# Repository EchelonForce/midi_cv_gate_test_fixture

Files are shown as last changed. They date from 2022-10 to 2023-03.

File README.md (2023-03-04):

# MIDI to 16x16 CV Gate Module Test Fixture

This the KiCAD design of a test fixture for the MIDI to 16x16 CV Gate Module

Full writeup here: https://www.robotdialogs.com/2023/03/test-fixture-and-calibration-eurorack.html

This work is licensed under a Creative Commons Attribution-NonCommercial-ShareAlike 4.0 International License. https://creativecommons.org/licenses/by-nc-sa/4.0/

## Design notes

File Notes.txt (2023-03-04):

Changed to 11k resistors to bring 10V under the 4.936 reference from the shunt diode.

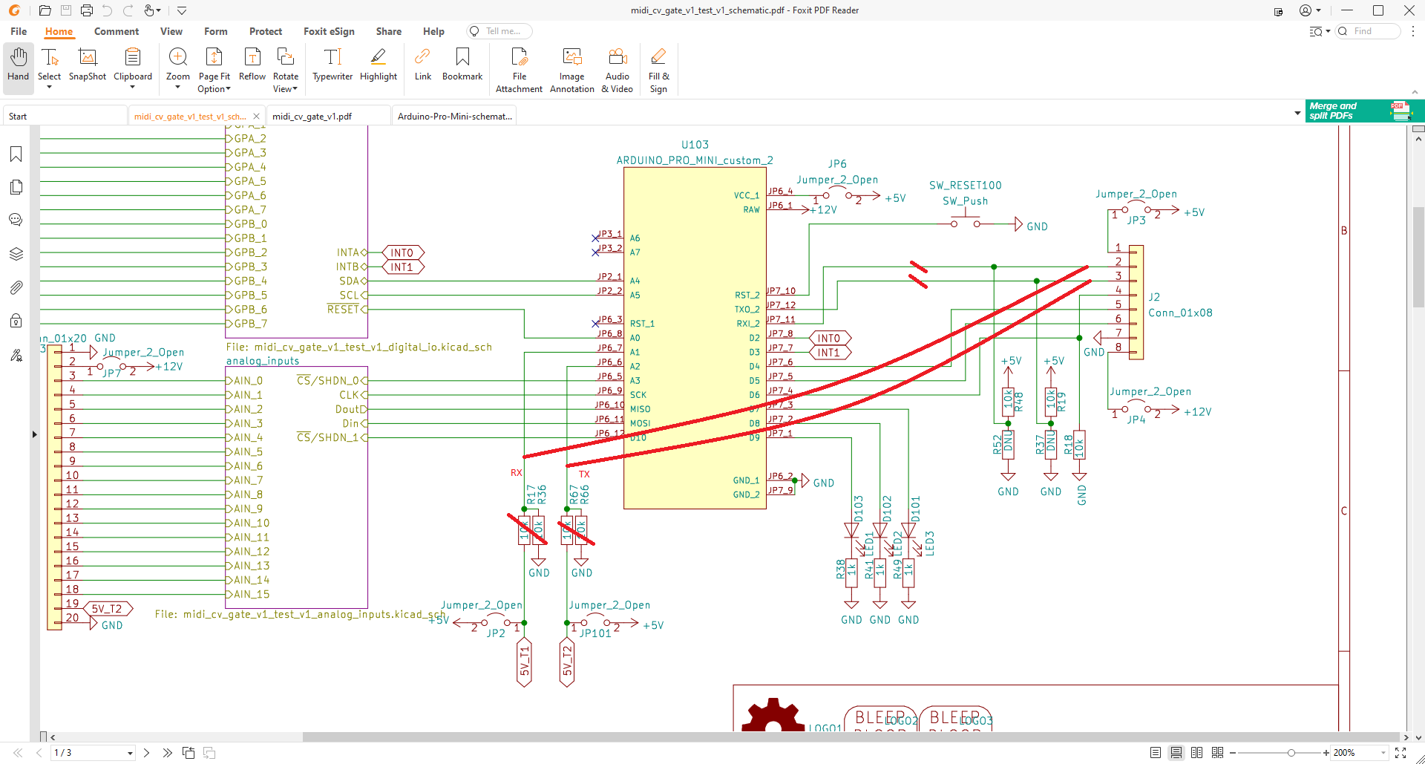
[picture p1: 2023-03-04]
Rework for Software Serial.png

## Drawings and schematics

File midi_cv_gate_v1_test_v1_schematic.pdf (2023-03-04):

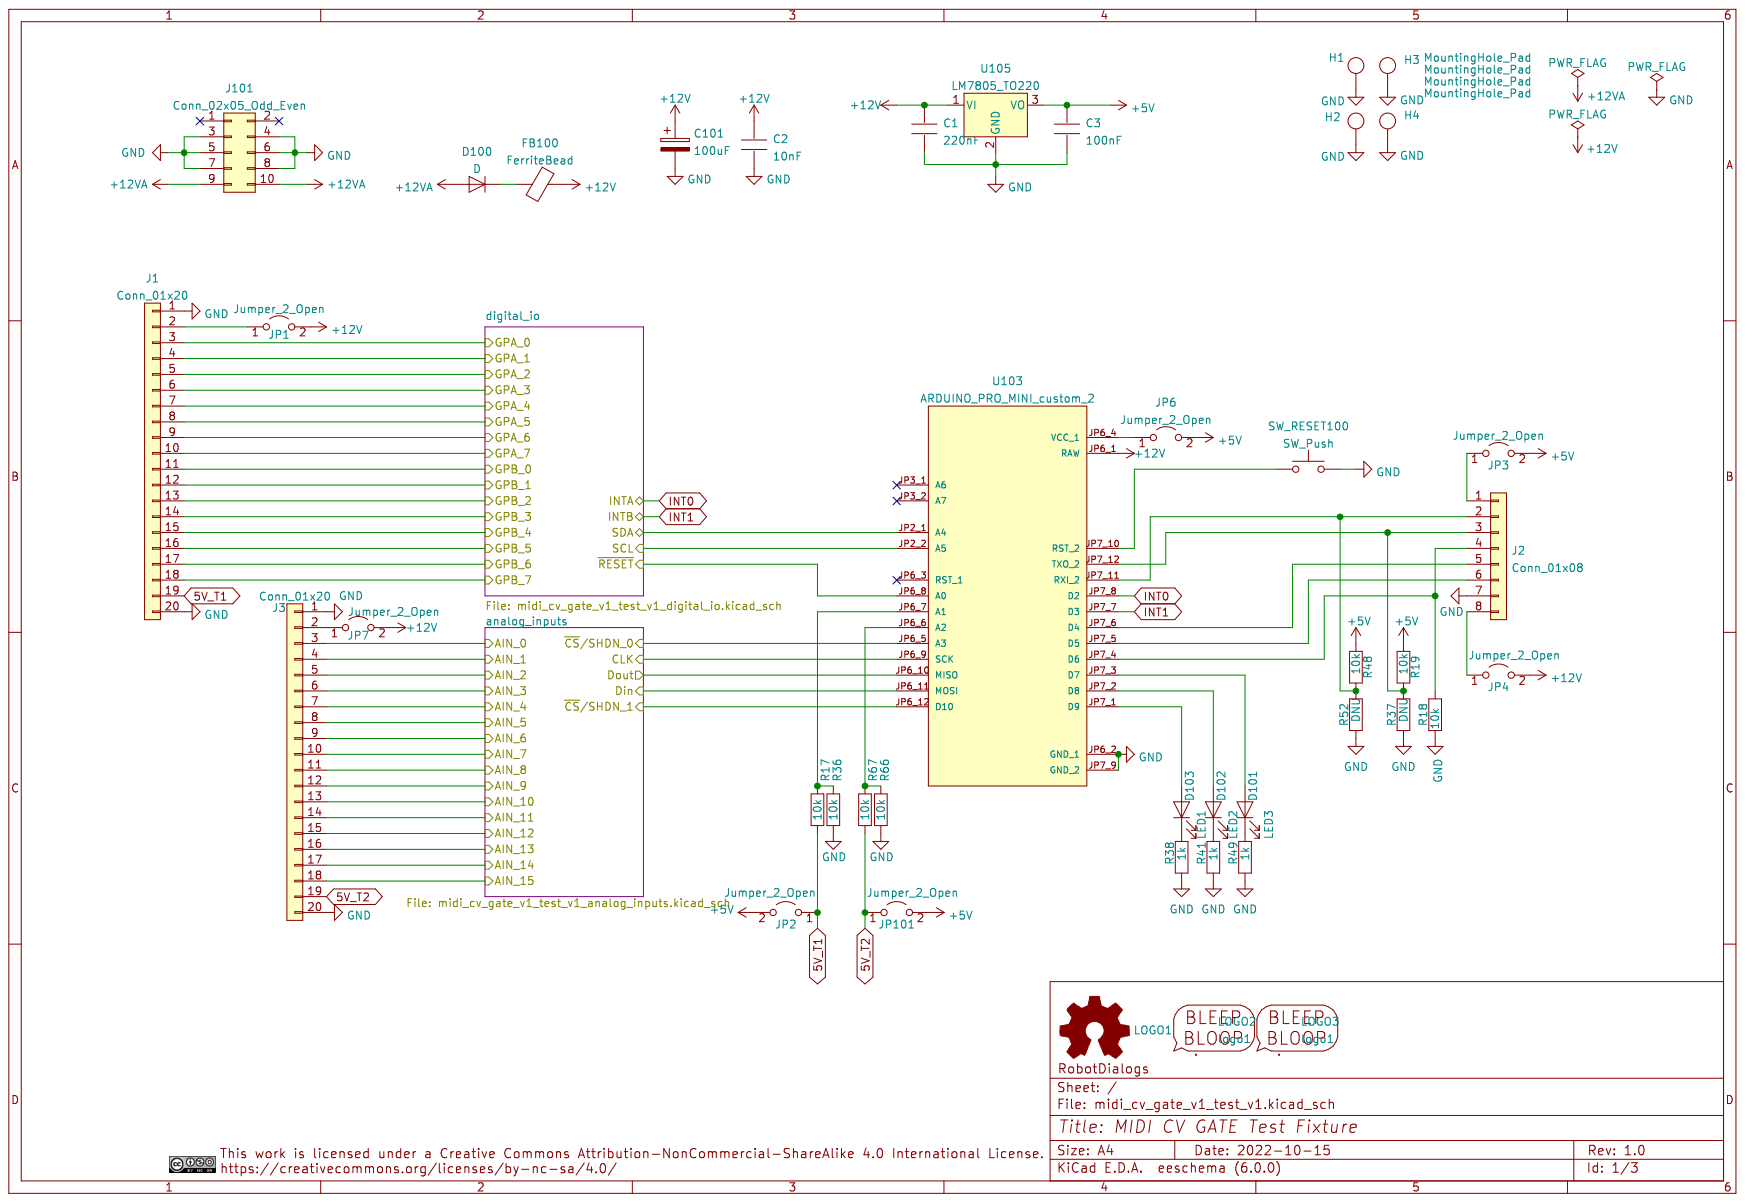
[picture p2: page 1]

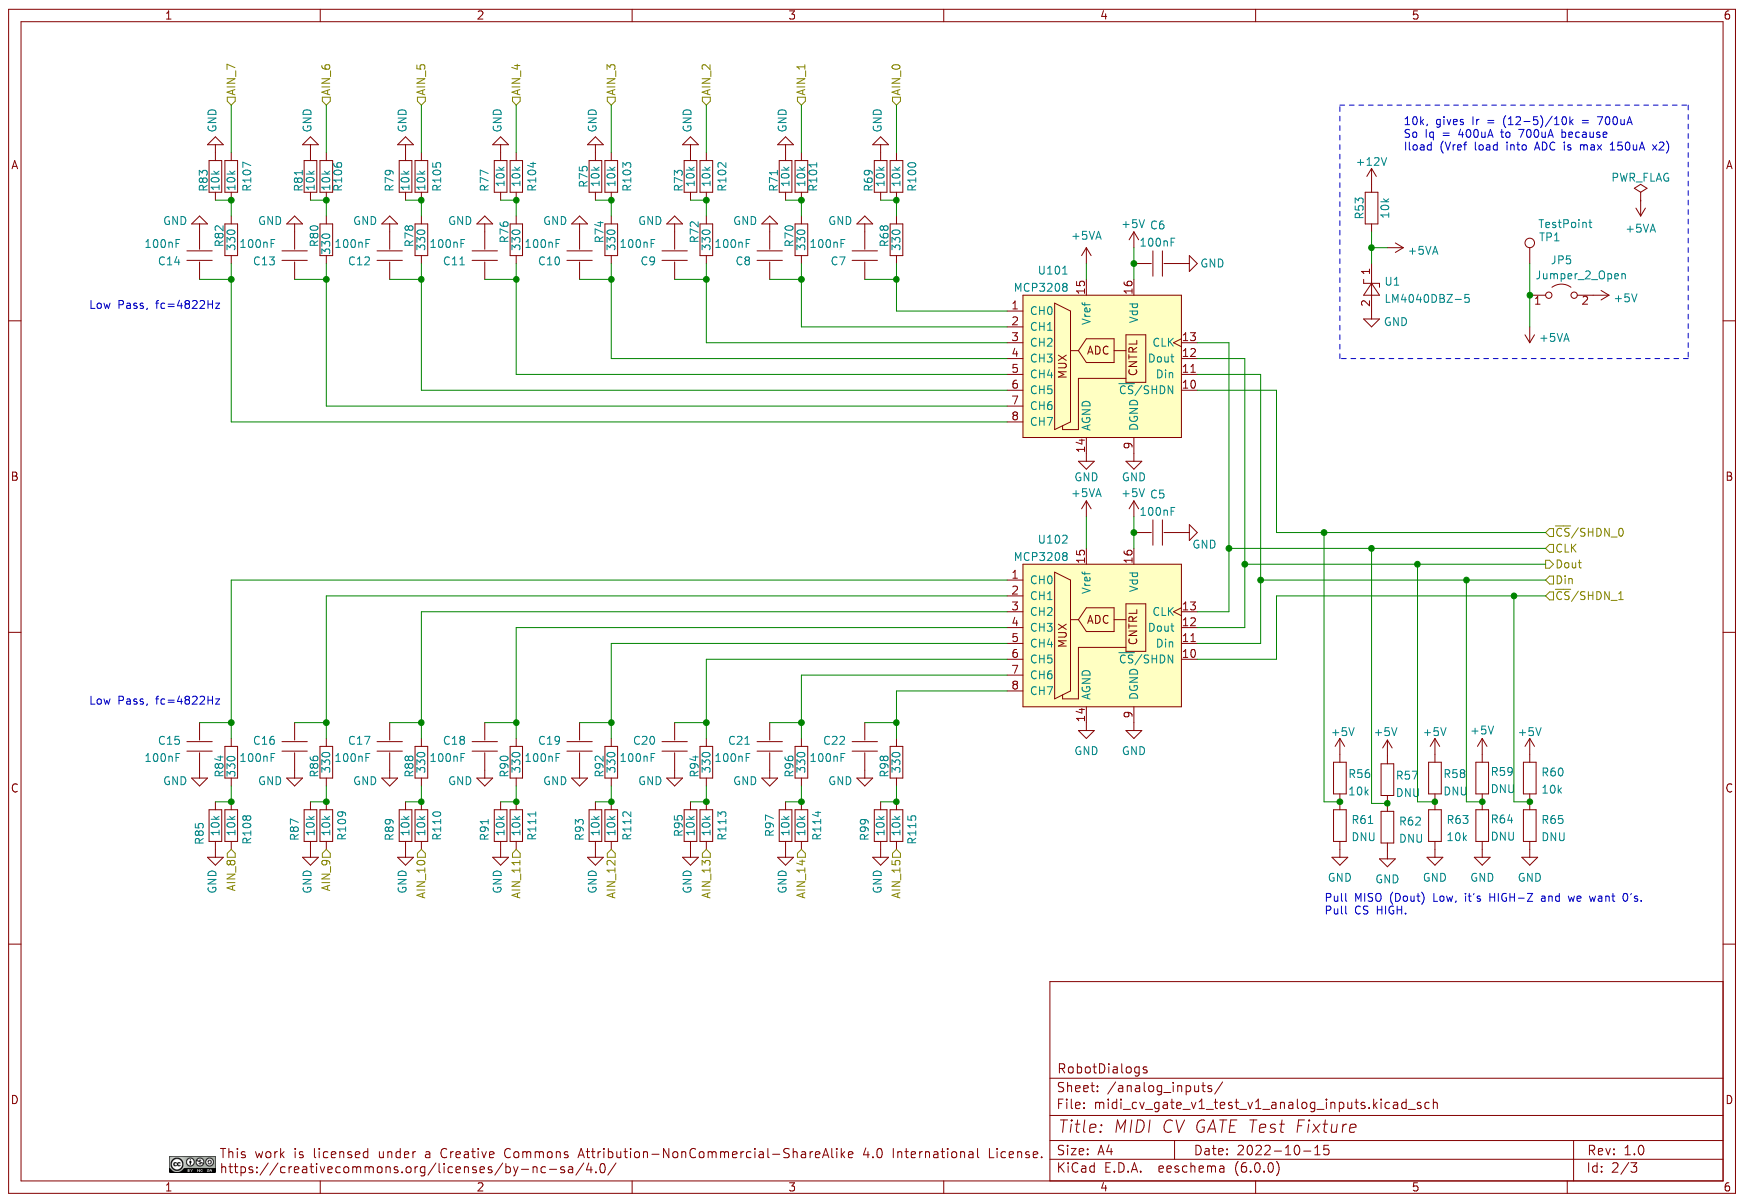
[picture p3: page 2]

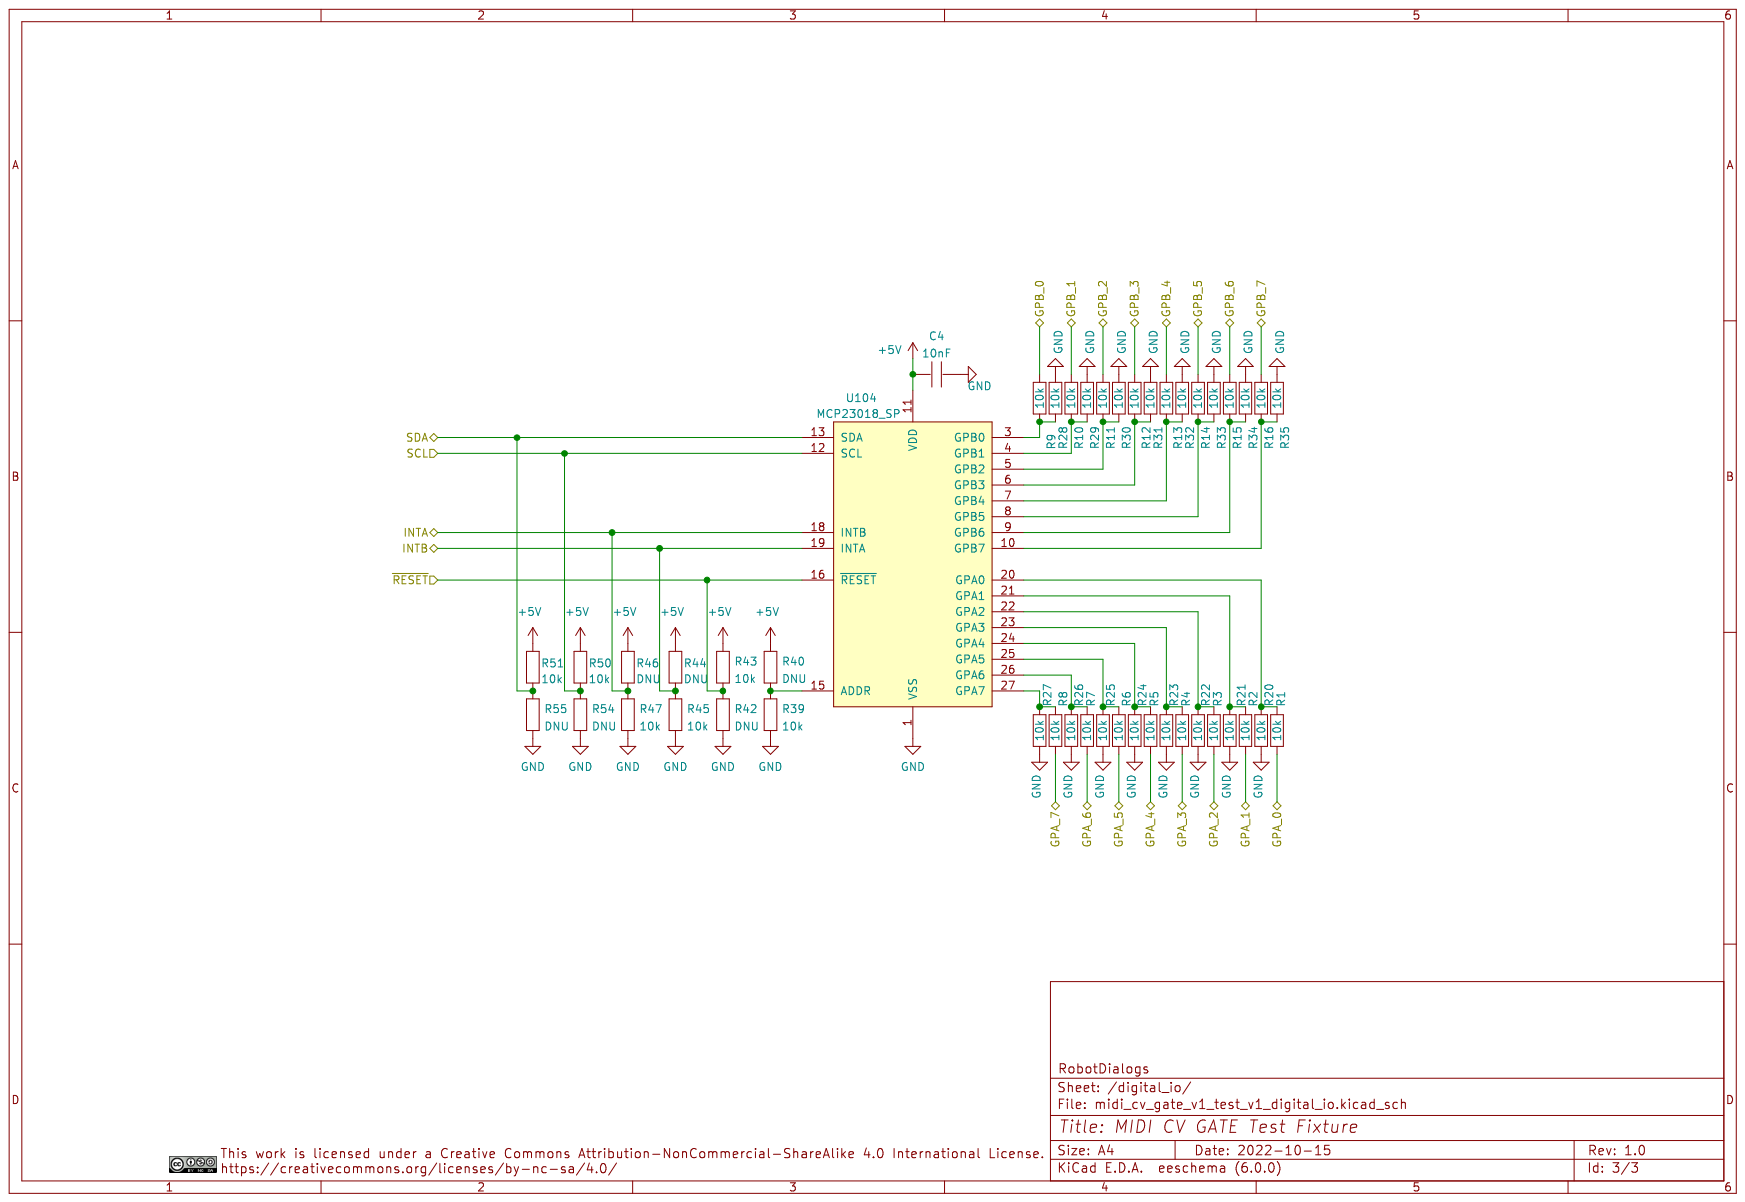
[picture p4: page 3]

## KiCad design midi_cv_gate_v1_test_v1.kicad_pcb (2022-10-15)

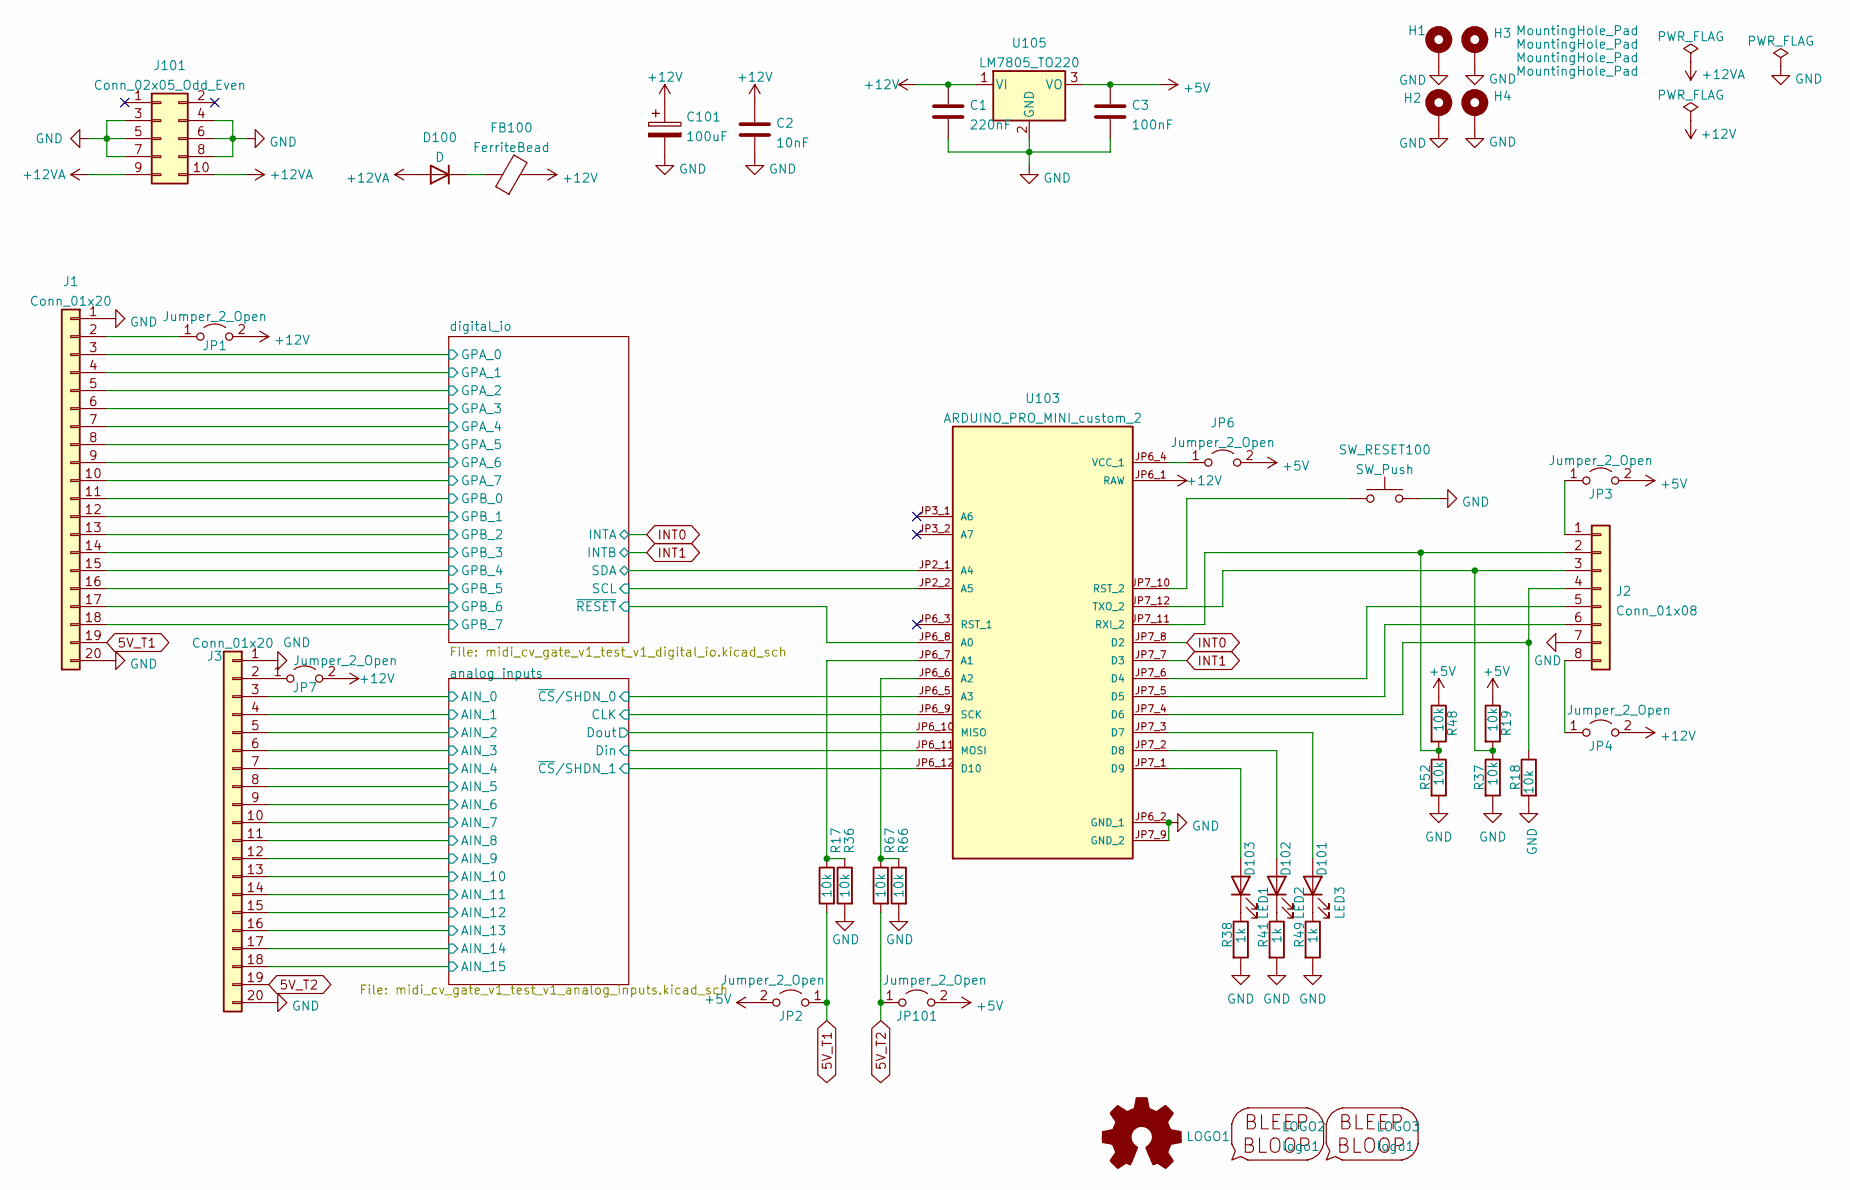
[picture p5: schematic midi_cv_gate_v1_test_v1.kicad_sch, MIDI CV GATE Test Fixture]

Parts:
C1: 220nF; C_1206_3216Metric_Pad1.33x1.80mm_HandSolder
C2: 10nF; C_1206_3216Metric_Pad1.33x1.80mm_HandSolder
C3: 100nF; C_1206_3216Metric_Pad1.33x1.80mm_HandSolder
C101: 100uF; CP_Radial_D5.0mm_P2.50mm
D100: D; D_A-405_P2.54mm_Vertical_KathodeUp
D101: LED3; LED_D3.0mm
D102: LED2; LED_D3.0mm
D103: LED1; LED_D3.0mm
FB100: FerriteBead; L_Axial_L6.6mm_D2.7mm_P2.54mm_Vertical_Vishay_IM-2
H1, H2, H3, H4: MountingHole_Pad; MountingHole_3.2mm_M3_ISO7380_Pad_TopBottom
J1, J3: Conn_01x20; PinSocket_1x20_P2.54mm_Vertical
J2: Conn_01x08; PinSocket_1x08_P2.54mm_Vertical
J101: Conn_02x05_Odd_Even; IDC-Header_2x05_P2.54mm_Vertical
JP1, JP2, JP3, JP4, JP6, JP7, JP101: Jumper_2_Open; SolderJumper-2_P1.3mm_Open_Pad1.0x1.5mm
LOGO1: Logo_Open_Hardware_Small; OSHW-Symbol_6.7x6mm_SilkScreen
LOGO2: logo1; Logo1
LOGO3: logo1; Logo2
R17, R18, R19, R36, R37, R48, R52, R66, R67: 10k; R_1206_3216Metric_Pad1.30x1.75mm_HandSolder
R38, R41, R49: 1k; R_1206_3216Metric_Pad1.30x1.75mm_HandSolder
SW_RESET100: SW_Push; SW_PUSH_6mm_H5mm
U103: ARDUINO_PRO_MINI_custom_2; MODULE_ARDUINO_PRO_MINI_custom_2; PARTREV N/A
U105: LM7805_TO220; TO-220-3_Horizontal_TabDown

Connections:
5V_T1: J1.19, JP2.1 (A), R17.2
5V_T2: J3.19, JP101.1 (A), R67.2
+5V: C3.1, JP2.2 (B), JP3.2 (B), JP6.2 (B), JP101.2 (B), R19.1, R48.1, U105.3 (VO); also elsewhere on the board
+12V: C1.1, C2.1, C101.1, FB100.2, JP1.2 (B), JP4.2 (B), JP7.2 (B), U103.JP6_1 (RAW), U105.1 (VI); also elsewhere on the board
+12VA: D100.2 (A), J101.9, J101.10
/analog_inputs/AIN_0: J3.3; also elsewhere on the board
/analog_inputs/AIN_1: J3.4; also elsewhere on the board
/analog_inputs/AIN_2: J3.5; also elsewhere on the board
/analog_inputs/AIN_3: J3.6; also elsewhere on the board
/analog_inputs/AIN_4: J3.7; also elsewhere on the board
/analog_inputs/AIN_5: J3.8; also elsewhere on the board
/analog_inputs/AIN_6: J3.9; also elsewhere on the board
/analog_inputs/AIN_7: J3.10; also elsewhere on the board
/analog_inputs/AIN_8: J3.11; also elsewhere on the board
/analog_inputs/AIN_9: J3.12; also elsewhere on the board
/analog_inputs/AIN_10: J3.13; also elsewhere on the board
/analog_inputs/AIN_11: J3.14; also elsewhere on the board
/analog_inputs/AIN_12: J3.15; also elsewhere on the board
/analog_inputs/AIN_13: J3.16; also elsewhere on the board
/analog_inputs/AIN_14: J3.17; also elsewhere on the board
/analog_inputs/AIN_15: J3.18; also elsewhere on the board
/analog_inputs/CLK: U103.JP6_9 (SCK); also elsewhere on the board
/analog_inputs/Din: U103.JP6_11 (MOSI); also elsewhere on the board
/analog_inputs/Dout: U103.JP6_10 (MISO); also elsewhere on the board
/analog_inputs/~CS/SHDN_0: U103.JP6_5 (A3); also elsewhere on the board
/analog_inputs/~CS/SHDN_1: U103.JP6_12 (D10); also elsewhere on the board
/digital_io/GPA_0: J1.3; also elsewhere on the board
/digital_io/GPA_1: J1.4; also elsewhere on the board
/digital_io/GPA_2: J1.5; also elsewhere on the board
/digital_io/GPA_3: J1.6; also elsewhere on the board
/digital_io/GPA_4: J1.7; also elsewhere on the board
/digital_io/GPA_5: J1.8; also elsewhere on the board
/digital_io/GPA_6: J1.9; also elsewhere on the board
/digital_io/GPA_7: J1.10; also elsewhere on the board
/digital_io/GPB_0: J1.11; also elsewhere on the board
/digital_io/GPB_1: J1.12; also elsewhere on the board
/digital_io/GPB_2: J1.13; also elsewhere on the board
/digital_io/GPB_3: J1.14; also elsewhere on the board
/digital_io/GPB_4: J1.15; also elsewhere on the board
/digital_io/GPB_5: J1.16; also elsewhere on the board
/digital_io/GPB_6: J1.17; also elsewhere on the board
/digital_io/GPB_7: J1.18; also elsewhere on the board
/digital_io/SCL: U103.JP2_2 (A5); also elsewhere on the board
/digital_io/SDA: U103.JP2_1 (A4); also elsewhere on the board
/digital_io/~RESET: U103.JP6_8 (A0); also elsewhere on the board
GND: C1.2, C2.2, C3.2, C101.2, H1.1, H2.1, H3.1, H4.1, J1.1, J1.20, J2.7, J3.1, J3.20, J101.3, J101.4, J101.5, J101.6, J101.7, J101.8, R18.2, R36.2, R37.2, R38.2, R41.2, R49.2, R52.2, R66.2, SW_RESET100.2, U103.JP6_2 (GND_1), U103.JP7_9 (GND_2), U105.2 (GND); also elsewhere on the board
INT0: U103.JP7_8 (D2); also elsewhere on the board
INT1: U103.JP7_7 (D3); also elsewhere on the board
unnamed: D100.1 (K), FB100.1
unnamed: D101.1 (K), R49.1
unnamed: D101.2 (A), U103.JP7_3 (D7)
unnamed: D102.1 (K), R41.1
unnamed: D102.2 (A), U103.JP7_2 (D8)
unnamed: D103.1 (K), R38.1
unnamed: D103.2 (A), U103.JP7_1 (D9)
unnamed: J1.2, JP1.1 (A)
unnamed: J2.1, JP3.1 (A)
unnamed: J2.2, R48.2, R52.1, U103.JP7_11 (RXI_2)
unnamed: J2.3, R18.1, R19.2, U103.JP7_12 (TXO_2)
unnamed: J2.4, R37.1, U103.JP7_4 (D6)
unnamed: J2.5, U103.JP7_6 (D4)
unnamed: J2.6, U103.JP7_5 (D5)
unnamed: J2.8, JP4.1 (A)
unnamed: J3.2, JP7.1 (A)
unnamed: JP6.1 (A), U103.JP6_4 (VCC_1)
unnamed: R17.1, R36.1, U103.JP6_7 (A1)
unnamed: R66.1, R67.1, U103.JP6_6 (A2)
unnamed: SW_RESET100.1, U103.JP7_10 (RST_2)

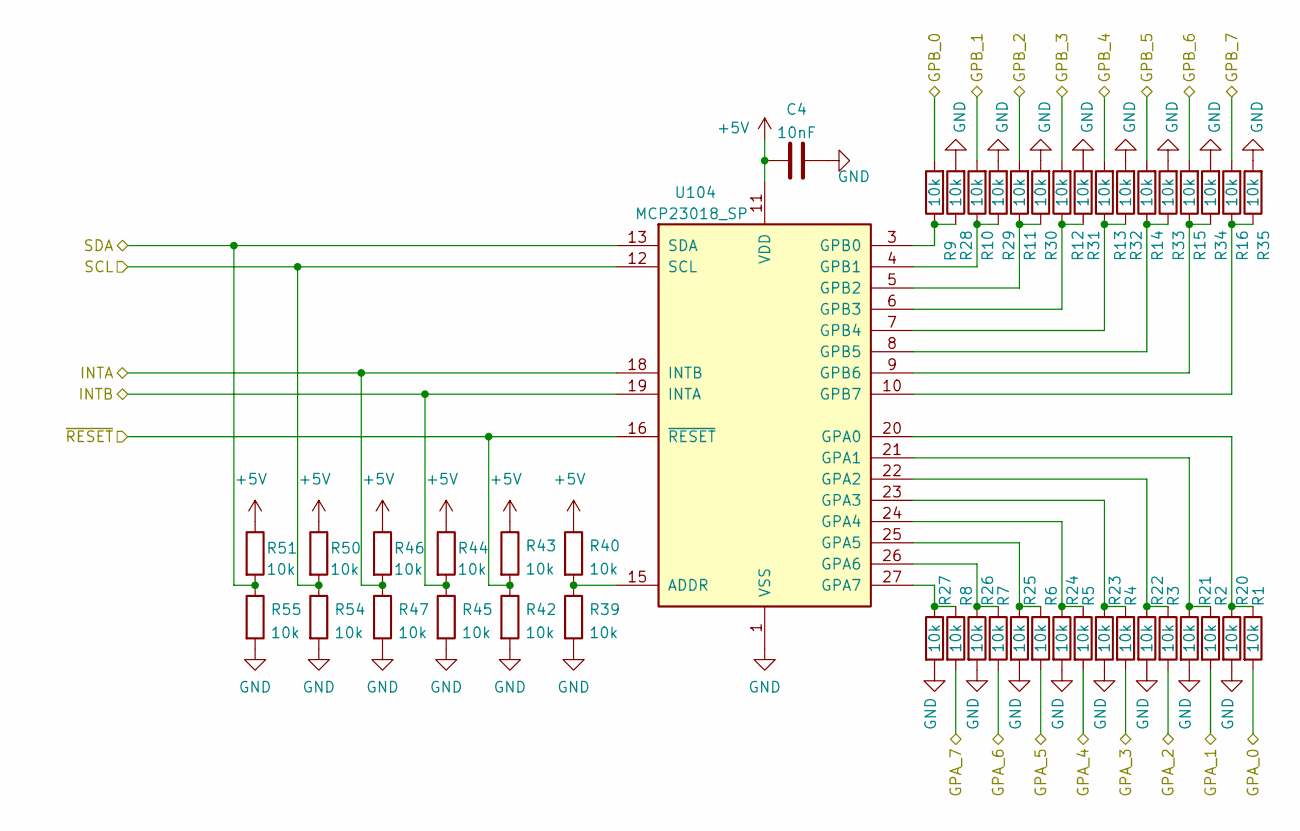
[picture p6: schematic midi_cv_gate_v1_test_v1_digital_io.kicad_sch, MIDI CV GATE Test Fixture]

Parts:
C4: 10nF; C_1206_3216Metric_Pad1.33x1.80mm_HandSolder
R1, R2, R3, R4, R5, R6, R7, R8, R9, R10, R11, R12, R13, R14, R15, R16, R20, R21, R22, R23, R24, R25, R26, R27, R28, R29, R30, R31, R32, R33, R34, R35, R39, R40, R42, R43, R44, R45, R46, R47, R50, R51, R54, R55: 10k; R_1206_3216Metric_Pad1.30x1.75mm_HandSolder
U104: MCP23018_SP; DIP-28_W7.62mm_Socket_LongPads

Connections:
+5V: C4.2, R40.1, R43.1, R44.1, R46.1, R50.1, R51.1, U104.11 (VDD); also elsewhere on the board
/digital_io/GPA_0: R1.2; also elsewhere on the board
/digital_io/GPA_1: R2.2; also elsewhere on the board
/digital_io/GPA_2: R3.2; also elsewhere on the board
/digital_io/GPA_3: R4.2; also elsewhere on the board
/digital_io/GPA_4: R5.2; also elsewhere on the board
/digital_io/GPA_5: R6.2; also elsewhere on the board
/digital_io/GPA_6: R7.2; also elsewhere on the board
/digital_io/GPA_7: R8.2; also elsewhere on the board
/digital_io/GPB_0: R9.2; also elsewhere on the board
/digital_io/GPB_1: R10.2; also elsewhere on the board
/digital_io/GPB_2: R11.2; also elsewhere on the board
/digital_io/GPB_3: R12.2; also elsewhere on the board
/digital_io/GPB_4: R13.2; also elsewhere on the board
/digital_io/GPB_5: R14.2; also elsewhere on the board
/digital_io/GPB_6: R15.2; also elsewhere on the board
/digital_io/GPB_7: R16.2; also elsewhere on the board
/digital_io/SCL: R50.2, R54.1, U104.12 (SCL); also elsewhere on the board
/digital_io/SDA: R51.2, R55.1, U104.13 (SDA); also elsewhere on the board
/digital_io/~RESET: R42.1, R43.2, U104.16 (~RESET); also elsewhere on the board
GND: C4.1, R20.2, R21.2, R22.2, R23.2, R24.2, R25.2, R26.2, R27.2, R28.2, R29.2, R30.2, R31.2, R32.2, R33.2, R34.2, R35.2, R39.2, R42.2, R45.2, R47.2, R54.2, R55.2, U104.1 (VSS); also elsewhere on the board
INT0: R46.2, R47.1, U104.18 (INTB); also elsewhere on the board
INT1: R44.2, R45.1, U104.19 (INTA); also elsewhere on the board
unnamed: R1.1, R20.1, U104.20 (GPA0)
unnamed: R2.1, R21.1, U104.21 (GPA1)
unnamed: R10.1, R29.1, U104.4 (GPB1)
unnamed: R11.1, R30.1, U104.5 (GPB2)
unnamed: R12.1, R31.1, U104.6 (GPB3)
unnamed: R13.1, R32.1, U104.7 (GPB4)
unnamed: R14.1, R33.1, U104.8 (GPB5)
unnamed: R15.1, R34.1, U104.9 (GPB6)
unnamed: R16.1, R35.1, U104.10 (GPB7)
unnamed: R3.1, R22.1, U104.22 (GPA2)
unnamed: R4.1, R23.1, U104.23 (GPA3)
unnamed: R5.1, R24.1, U104.24 (GPA4)
unnamed: R6.1, R25.1, U104.25 (GPA5)
unnamed: R7.1, R26.1, U104.26 (GPA6)
unnamed: R8.1, R27.1, U104.27 (GPA7)
unnamed: R9.1, R28.1, U104.3 (GPB0)
unnamed: R39.1, R40.2, U104.15 (ADDR)

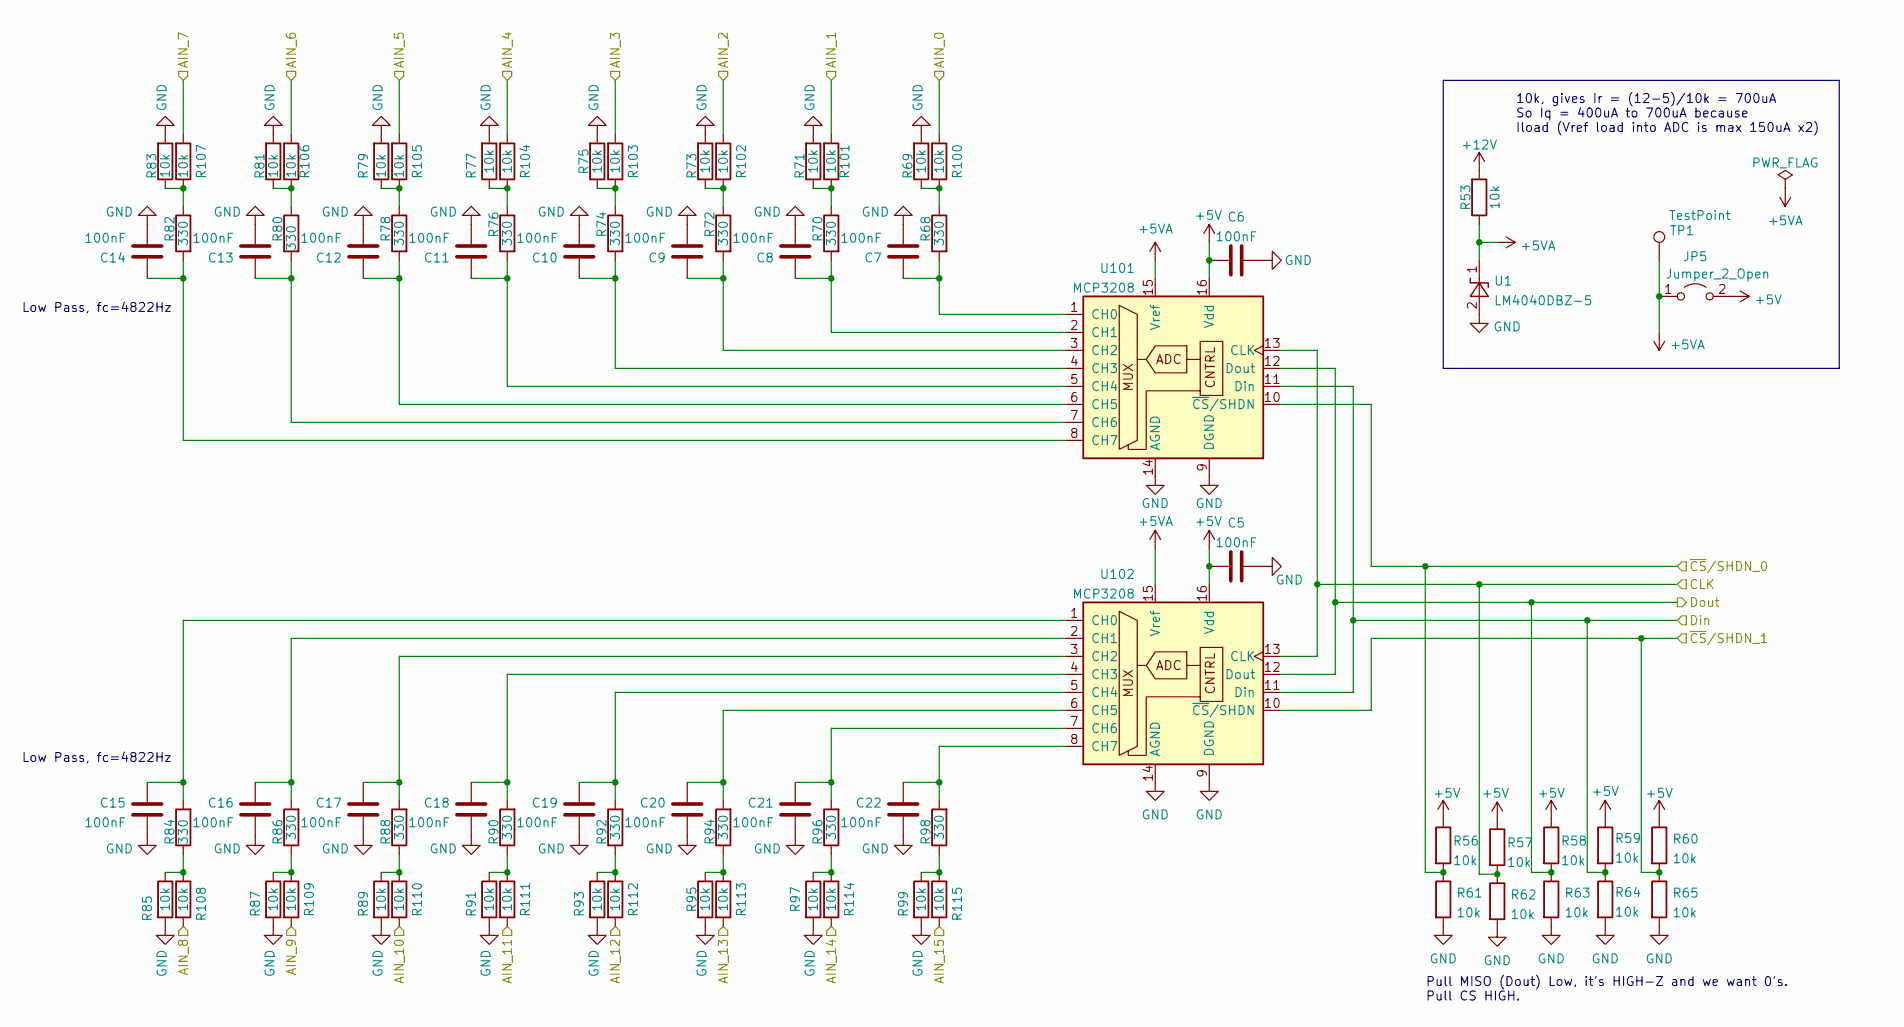
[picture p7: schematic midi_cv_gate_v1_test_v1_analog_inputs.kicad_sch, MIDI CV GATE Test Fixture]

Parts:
C5, C6, C7, C8, C9, C10, C11, C12, C13, C14, C15, C16, C17, C18, C19, C20, C21, C22: 100nF; C_1206_3216Metric_Pad1.33x1.80mm_HandSolder
JP5: Jumper_2_Open; SolderJumper-2_P1.3mm_Open_Pad1.0x1.5mm
R53, R56, R57, R58, R59, R60, R61, R62, R63, R64, R65, R69, R71, R73, R75, R77, R79, R81, R83, R85, R87, R89, R91, R93, R95, R97, R99, R100, R101, R102, R103, R104, R105, R106, R107, R108, R109, R110, R111, R112, R113, R114, R115: 10k; R_1206_3216Metric_Pad1.30x1.75mm_HandSolder
R68, R70, R72, R74, R76, R78, R80, R82, R84, R86, R88, R90, R92, R94, R96, R98: 330; R_1206_3216Metric_Pad1.30x1.75mm_HandSolder
TP1: TestPoint; TestPoint_THTPad_2.0x2.0mm_Drill1.0mm
U1: LM4040DBZ-5; SOT-23
U101, U102: MCP3208; DIP-16_W7.62mm_Socket_LongPads

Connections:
+5V: C5.2, C6.2, JP5.2 (B), R56.1, R57.1, R58.1, R59.1, R60.1, U101.16 (Vdd), U102.16 (Vdd); also elsewhere on the board
+5VA: JP5.1 (A), R53.1, TP1.1, U1.1 (K), U101.15 (Vref), U102.15 (Vref)
+12V: R53.2; also elsewhere on the board
/analog_inputs/AIN_0: R100.2; also elsewhere on the board
/analog_inputs/AIN_1: R101.2; also elsewhere on the board
/analog_inputs/AIN_2: R102.2; also elsewhere on the board
/analog_inputs/AIN_3: R103.2; also elsewhere on the board
/analog_inputs/AIN_4: R104.2; also elsewhere on the board
/analog_inputs/AIN_5: R105.2; also elsewhere on the board
/analog_inputs/AIN_6: R106.2; also elsewhere on the board
/analog_inputs/AIN_7: R107.2; also elsewhere on the board
/analog_inputs/AIN_8: R108.2; also elsewhere on the board
/analog_inputs/AIN_9: R109.2; also elsewhere on the board
/analog_inputs/AIN_10: R110.2; also elsewhere on the board
/analog_inputs/AIN_11: R111.2; also elsewhere on the board
/analog_inputs/AIN_12: R112.2; also elsewhere on the board
/analog_inputs/AIN_13: R113.2; also elsewhere on the board
/analog_inputs/AIN_14: R114.2; also elsewhere on the board
/analog_inputs/AIN_15: R115.2; also elsewhere on the board
/analog_inputs/CLK: R57.2, R62.1, U101.13 (CLK), U102.13 (CLK); also elsewhere on the board
/analog_inputs/Din: R59.2, R64.1, U101.11 (Din), U102.11 (Din); also elsewhere on the board
/analog_inputs/Dout: R58.2, R63.1, U101.12 (Dout), U102.12 (Dout); also elsewhere on the board
/analog_inputs/~CS/SHDN_0: R56.2, R61.1, U101.10 (~CS/SHDN); also elsewhere on the board
/analog_inputs/~CS/SHDN_1: R60.2, R65.1, U102.10 (~CS/SHDN); also elsewhere on the board
GND: C5.1, C6.1, C7.2, C8.2, C9.2, C10.2, C11.2, C12.2, C13.2, C14.2, C15.2, C16.2, C17.2, C18.2, C19.2, C20.2, C21.2, C22.2, R61.2, R62.2, R63.2, R64.2, R65.2, R69.2, R71.2, R73.2, R75.2, R77.2, R79.2, R81.2, R83.2, R85.2, R87.2, R89.2, R91.2, R93.2, R95.2, R97.2, R99.2, U1.2 (A), U101.9 (DGND), U101.14 (AGND), U102.9 (DGND), U102.14 (AGND); also elsewhere on the board
unnamed: C7.1, R68.2, U101.1 (CH0)
unnamed: C8.1, R70.2, U101.2 (CH1)
unnamed: C9.1, R72.2, U101.3 (CH2)
unnamed: C10.1, R74.2, U101.4 (CH3)
unnamed: C11.1, R76.2, U101.5 (CH4)
unnamed: C12.1, R78.2, U101.6 (CH5)
unnamed: C13.1, R80.2, U101.7 (CH6)
unnamed: C14.1, R82.2, U101.8 (CH7)
unnamed: C15.1, R84.2, U102.1 (CH0)
unnamed: C16.1, R86.2, U102.2 (CH1)
unnamed: C17.1, R88.2, U102.3 (CH2)
unnamed: C18.1, R90.2, U102.4 (CH3)
unnamed: C19.1, R92.2, U102.5 (CH4)
unnamed: C20.1, R94.2, U102.6 (CH5)
unnamed: C21.1, R96.2, U102.7 (CH6)
unnamed: C22.1, R98.2, U102.8 (CH7)
unnamed: R68.1, R69.1, R100.1
unnamed: R70.1, R71.1, R101.1
unnamed: R72.1, R73.1, R102.1
unnamed: R74.1, R75.1, R103.1
unnamed: R76.1, R77.1, R104.1
unnamed: R78.1, R79.1, R105.1
unnamed: R80.1, R81.1, R106.1
unnamed: R82.1, R83.1, R107.1
unnamed: R84.1, R85.1, R108.1
unnamed: R86.1, R87.1, R109.1
unnamed: R88.1, R89.1, R110.1
unnamed: R90.1, R91.1, R111.1
unnamed: R92.1, R93.1, R112.1
unnamed: R94.1, R95.1, R113.1
unnamed: R96.1, R97.1, R114.1
unnamed: R98.1, R99.1, R115.1

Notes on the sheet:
10k, gives Ir = (12-5)/10k = 700uA So Iq = 400uA to 700uA because Iload (Vref load into ADC is max 150uA x2)
Pull MISO (Dout) Low, it's HIGH-Z and we want 0's. Pull CS HIGH.
Low Pass, fc=4822Hz

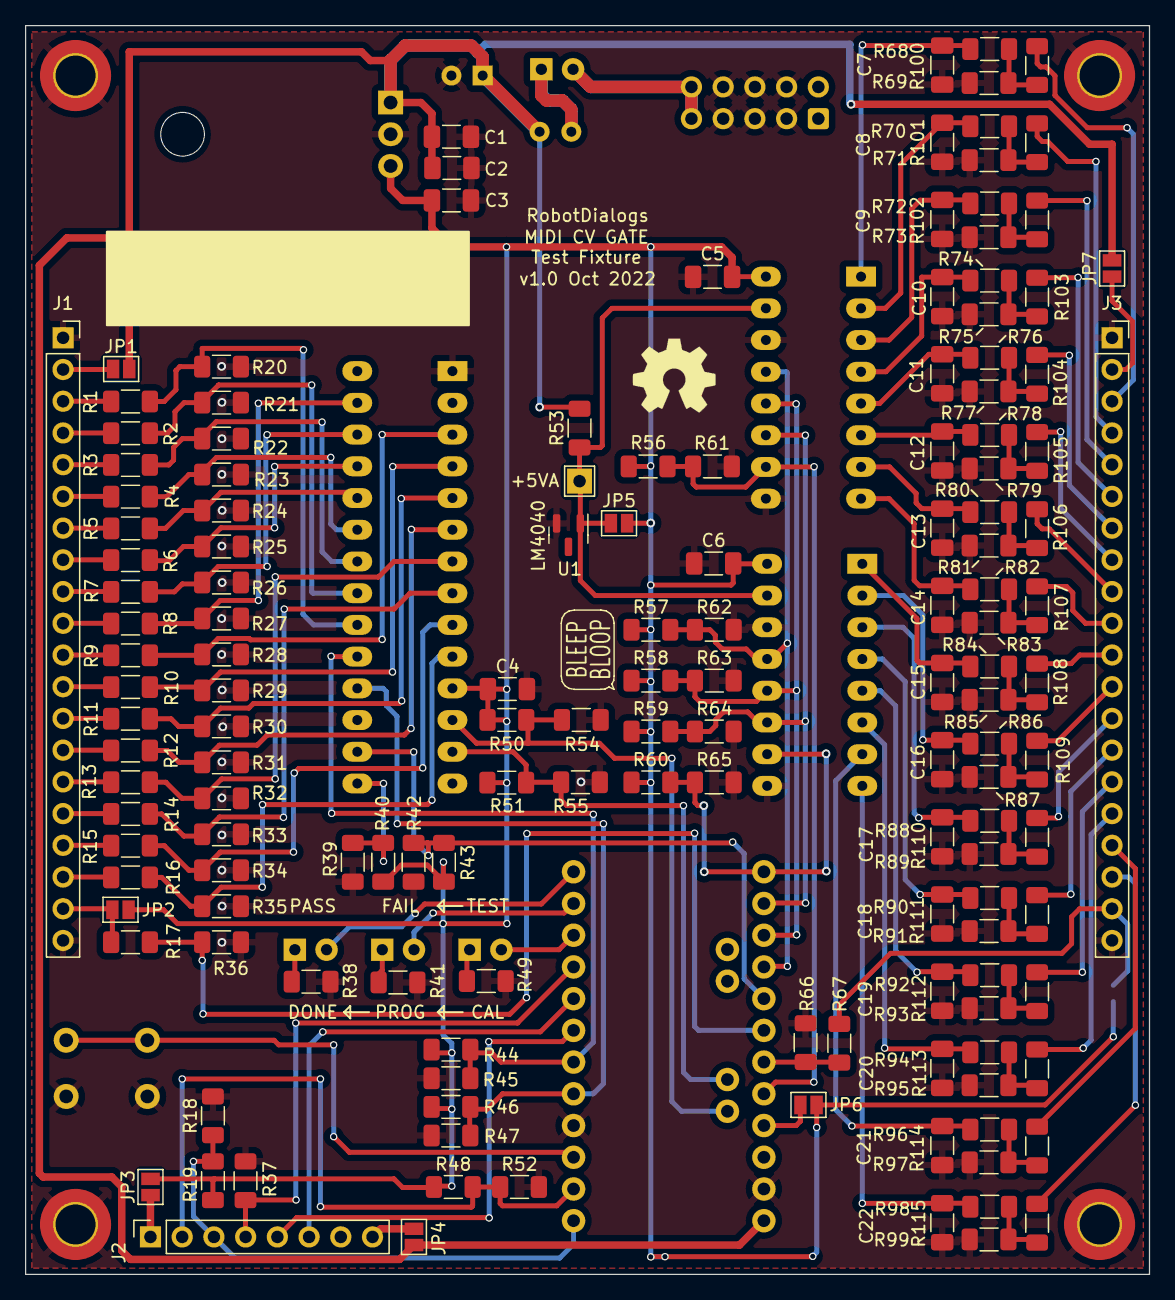
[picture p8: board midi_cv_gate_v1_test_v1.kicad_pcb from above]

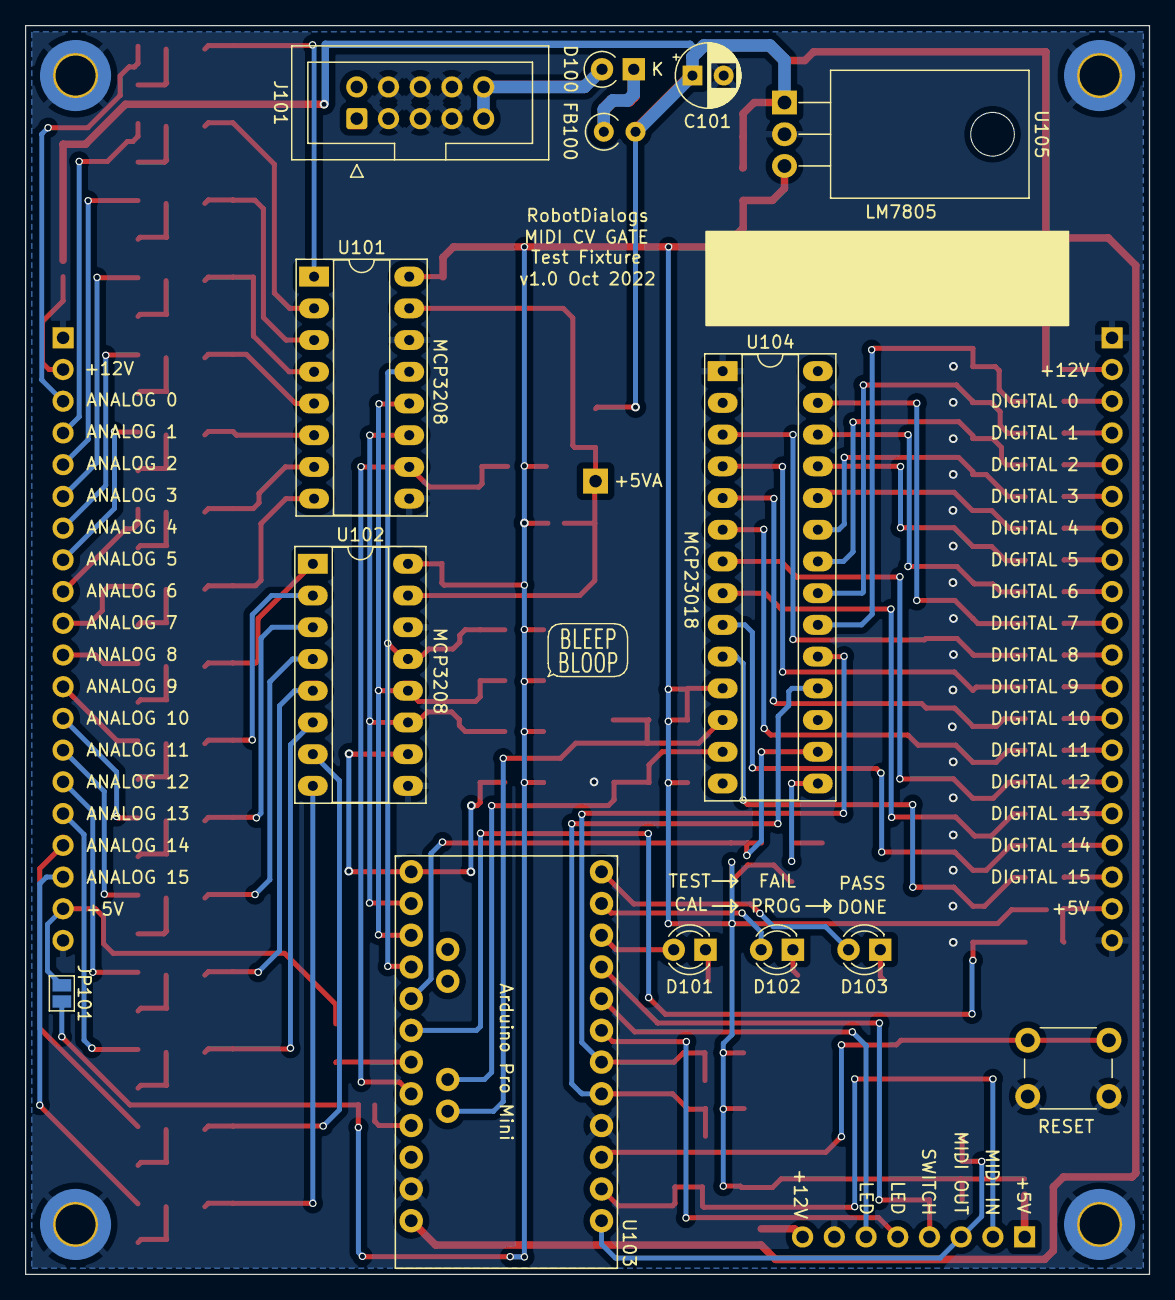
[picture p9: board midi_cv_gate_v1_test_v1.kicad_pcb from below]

Board: 2 copper layers, 90.0 x 100.0 mm, 170 parts (14 on the bottom side), 118 nets.

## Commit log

2022-10-01 Schematic mostly figured out
    [midi_cv_gate_v1_test_v1.kicad_pcb, midi_cv_gate_v1_test_v1.kicad_sch, midi_cv_gate_v1_test_v1_analog_inputs.kicad_sch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]
2022-10-02 Component positions first draft
    [midi_cv_gate_v1_test_v1.kicad_pcb, midi_cv_gate_v1_test_v1.kicad_sch, midi_cv_gate_v1_test_v1_analog_inputs.kicad_sch]
2022-10-02 First pass routing done
    [midi_cv_gate_v1_test_v1.kicad_pcb, midi_cv_gate_v1_test_v1.kicad_sch, midi_cv_gate_v1_test_v1_analog_inputs.kicad_sch]
2022-10-02 Geographic re-annotate
    [midi_cv_gate_v1_test_v1.kicad_pcb, midi_cv_gate_v1_test_v1.kicad_sch, midi_cv_gate_v1_test_v1_analog_inputs.kicad_sch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]
2022-10-02 Silkscreen cleanup and title block filled
    [midi_cv_gate_v1_test_v1.kicad_pcb]
2022-10-10 A little cleanup
    [midi_cv_gate_v1_test_v1.kicad_pcb, midi_cv_gate_v1_test_v1.kicad_sch, midi_cv_gate_v1_test_v1_analog_inputs.kicad_sch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]
2022-10-10 Output script for v1
    [midi_cv_gate_v1_test_v1.kicad_pcb]
2022-10-15 Resync pcb and schematic
    [midi_cv_gate_v1_test_v1.kicad_pcb, midi_cv_gate_v1_test_v1.kicad_sch, midi_cv_gate_v1_test_v1_analog_inputs.kicad_sch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]
2022-10-15 Add schematic pdf
2023-03-04 Component updates and rework info v1
    [midi_cv_gate_v1_test_v1.kicad_sch, midi_cv_gate_v1_test_v1_analog_inputs.kicad_sch, midi_cv_gate_v1_test_v1_digital_io.kicad_sch]
